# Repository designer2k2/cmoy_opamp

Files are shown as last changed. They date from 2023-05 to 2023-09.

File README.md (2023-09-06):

# cmoy_opamp
flexible cmoy style headphone amplifier

it can fit dual or single Op Amp´s, even a ZIF socket is possible for fast Op Amp changes.

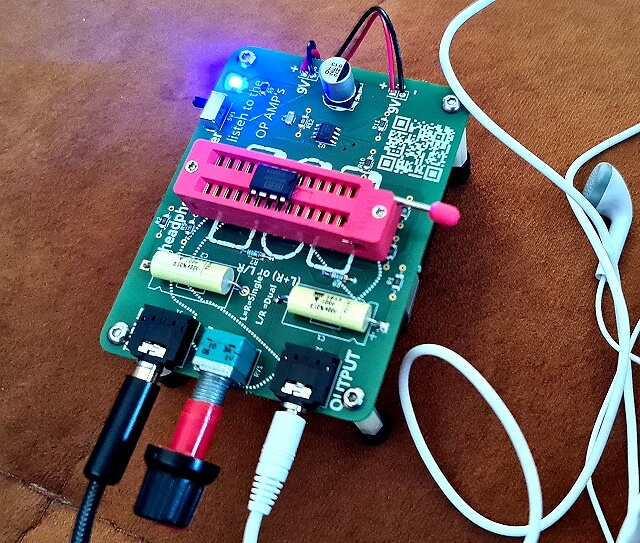
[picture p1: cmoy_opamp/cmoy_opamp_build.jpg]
cmoy schematic


## The schematics:
cmoy schematic
It looks a bit strange, but its to fit both SMD and THT parts, and the different Op Amps.

One selection was made specifically, thats the virtual ground with a resistor voltage divider and voltage follower with the LMH6642. Like this it adds another Op Amp, fitting the Op Amp challenge better.

## PCB:
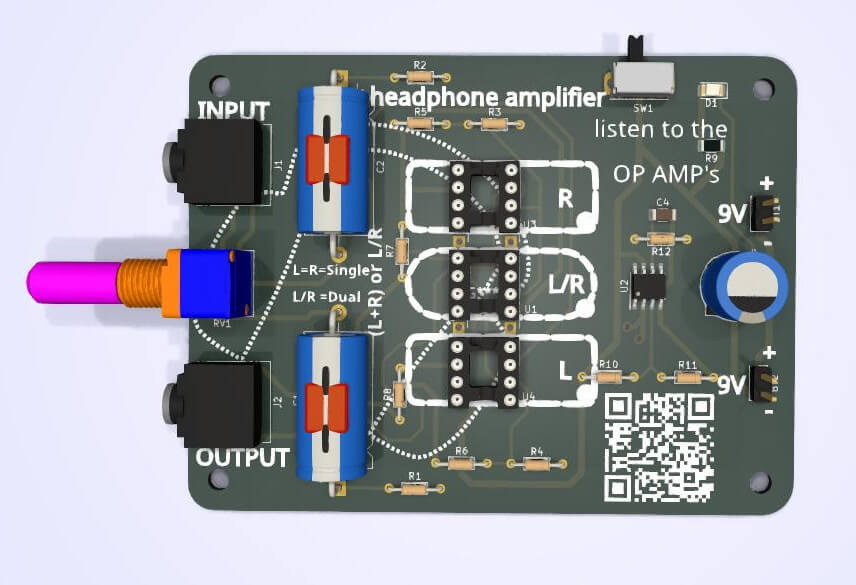
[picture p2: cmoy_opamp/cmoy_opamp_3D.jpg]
cmoy schematic


its made to fit single or dual Op Amps:

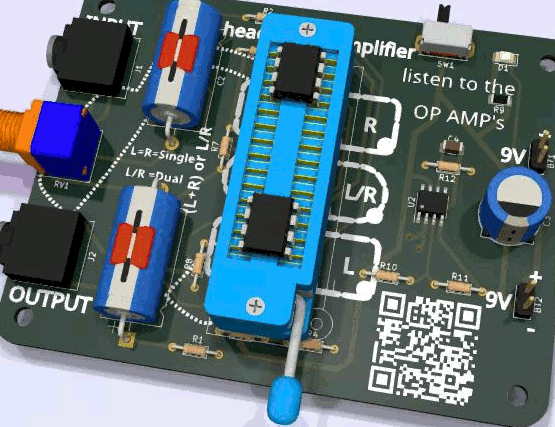
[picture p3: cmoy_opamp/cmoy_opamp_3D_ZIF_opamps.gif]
cmoy schematic


To listen to many different IC´s a ZIF Socket is helpful:

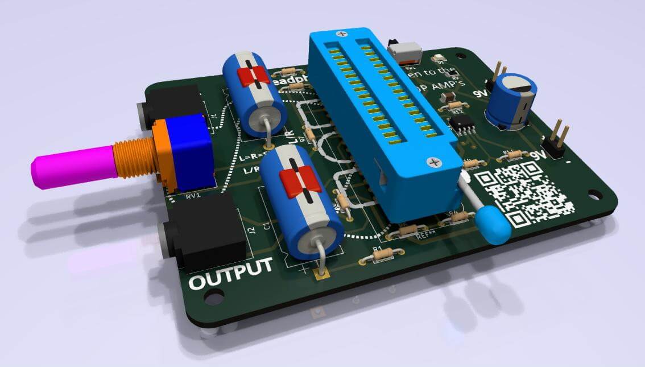
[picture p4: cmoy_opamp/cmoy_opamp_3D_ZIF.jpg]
cmoy schematic


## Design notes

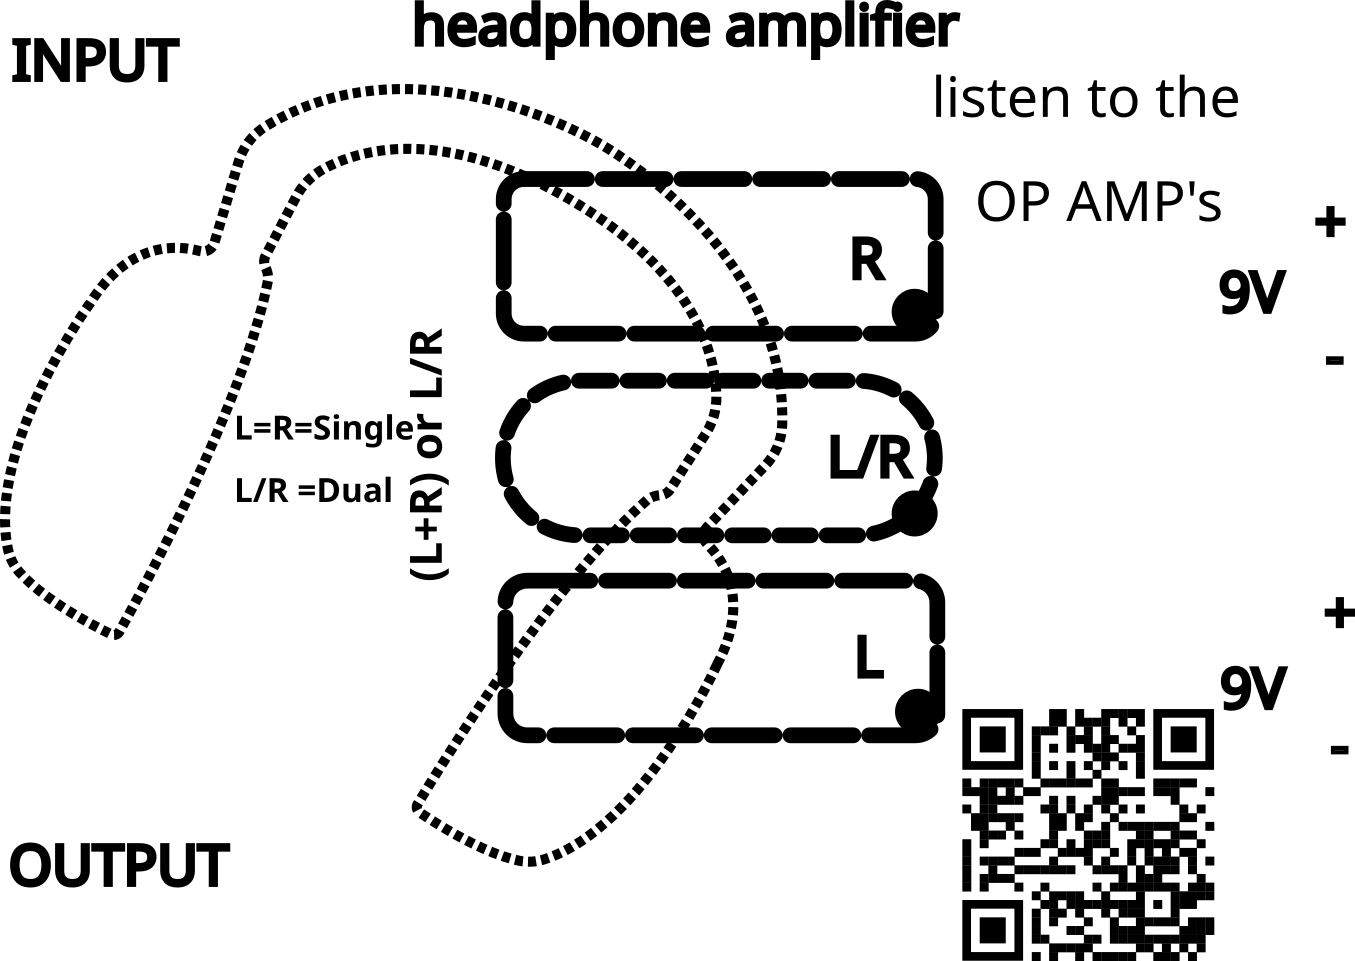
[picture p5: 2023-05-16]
cmoy_opamp/cmoy_opamp-brd.png

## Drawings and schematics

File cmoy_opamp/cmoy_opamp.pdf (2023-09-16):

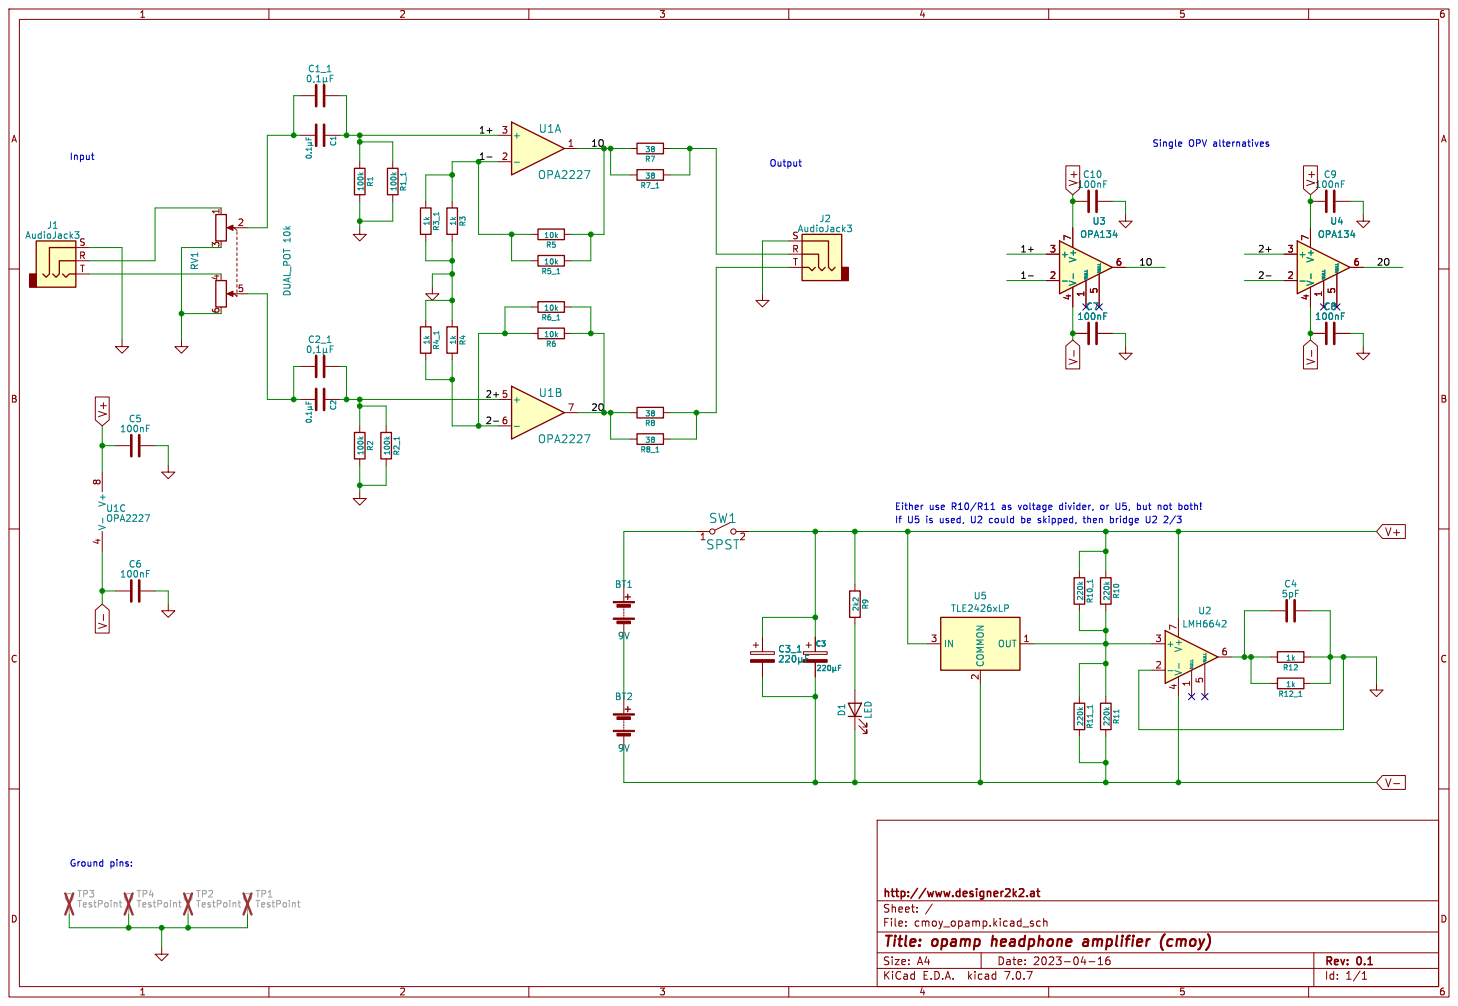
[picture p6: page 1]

If U5 is used, U2 could be skipped, then bridge U2 2/3 C7

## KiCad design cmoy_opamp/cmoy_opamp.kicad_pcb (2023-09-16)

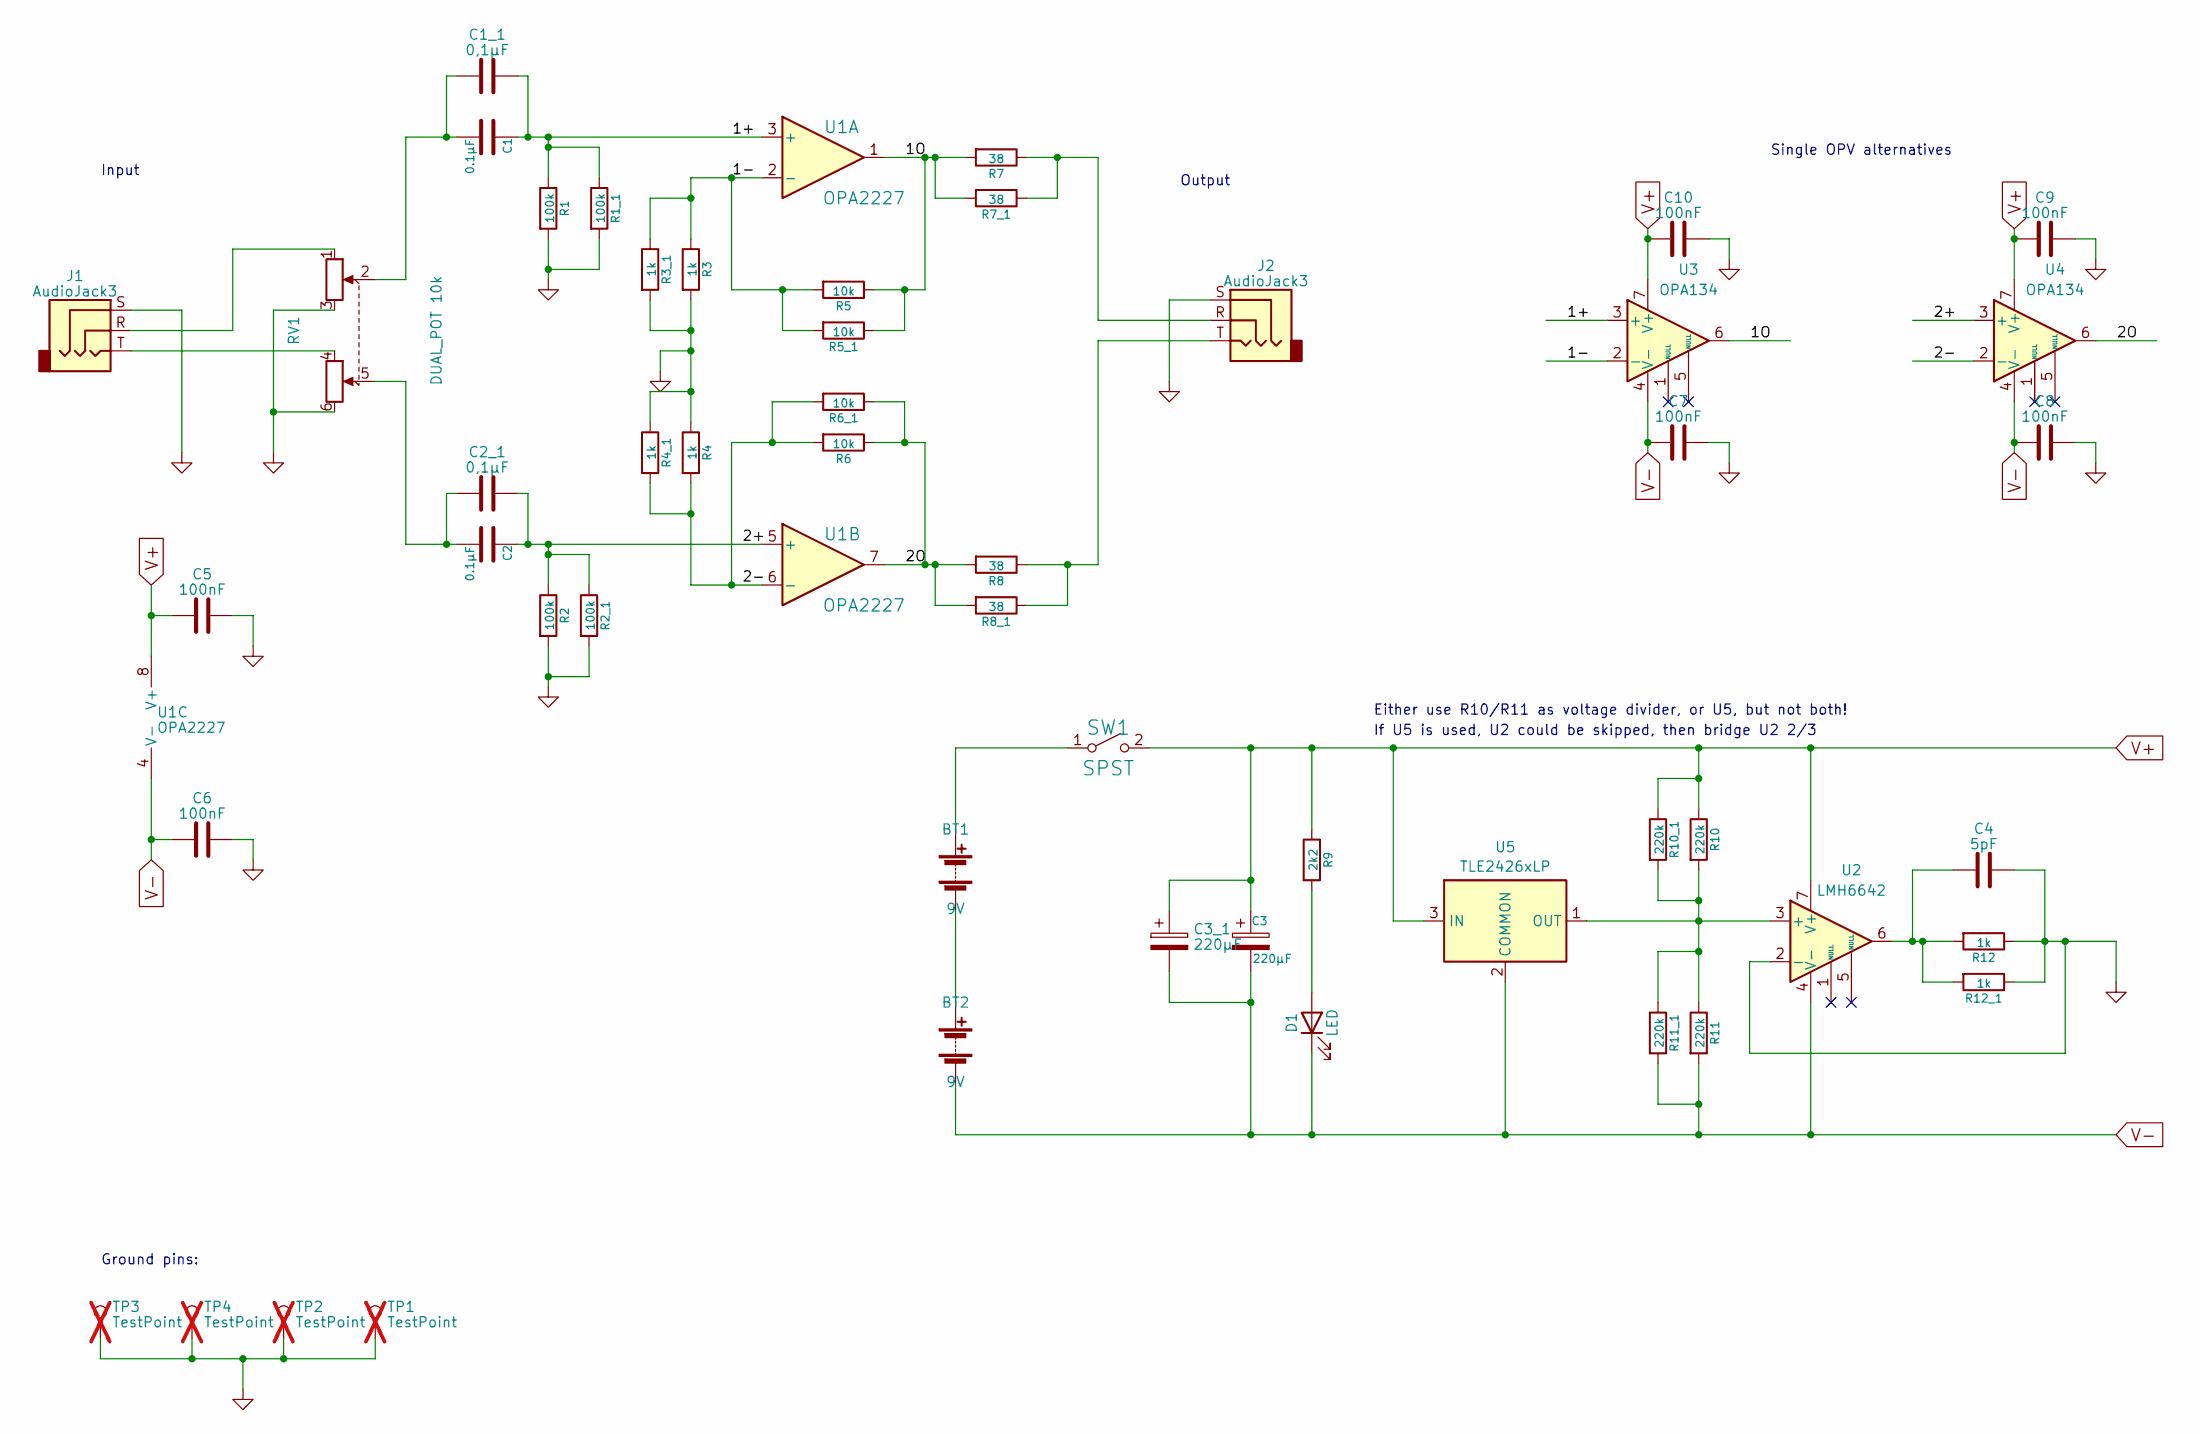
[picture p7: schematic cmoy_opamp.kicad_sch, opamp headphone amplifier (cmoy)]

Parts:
BT1, BT2: 9V; PinHeader_2x01_P2.54mm_Vertical
C1, C2: 0.1µF; CP_Axial_L20.0mm_D10.0mm_P26.00mm_Horizontal; Part MKT1813410405
C1_1, C2_1: 0,1µF; C_Rect_L7.0mm_W6.0mm_P5.00mm; Part BFC237011105
C3: 220µF; CP_Elec_8x10
C3_1: 220µF; CP_Radial_D10.0mm_P3.50mm
C4: 5pF; C_1206_3216Metric
C5, C6, C7, C8, C9, C10: 100nF; C_1206_3216Metric
D1: LED; LED_1206_3216Metric
J1, J2: AudioJack3; Jack_3.5mm_CUI_SJ1-3523N_Horizontal; Part SJ1-3523N
R1, R2: 100k; R_1206_3216Metric
R1_1, R2_1: 100k; R_Axial_DIN0204_L3.6mm_D1.6mm_P7.62mm_Horizontal
R3, R4, R12: 1k; R_1206_3216Metric
R3_1, R4_1, R12_1: 1k; R_Axial_DIN0204_L3.6mm_D1.6mm_P7.62mm_Horizontal
R5, R6: 10k; R_1206_3216Metric
R5_1, R6_1: 10k; R_Axial_DIN0204_L3.6mm_D1.6mm_P7.62mm_Horizontal
R7, R8: 38; R_1206_3216Metric
R7_1, R8_1: 38; R_Axial_DIN0204_L3.6mm_D1.6mm_P7.62mm_Horizontal
R9: 2k2; R_1206_3216Metric
R10, R11: 220k; R_1206_3216Metric
R10_1, R11_1: 220k; R_Axial_DIN0204_L3.6mm_D1.6mm_P7.62mm_Horizontal
RV1: DUAL_POT 10k; Potentiometer_Alps_RK097_Dual_Horizontal; Part RK09712200HA
SW1: SPST; SW_CuK_OS102011MA1QN1_SPDT_Angled; Part OS102011MA1QN1
TP1, TP2, TP3, TP4: TestPoint; PinSocket_1x01_P2.54mm_Vertical; not fitted
U1: OPA2227; DIP-8_W7.62mm_Socket
U2: LMH6642; SOIC-8_3.9x4.9mm_P1.27mm; Part LMH6642MA
U3, U4: OPA134; DIP-8_W7.62mm_Socket
U5: TLE2426xLP; TO-92

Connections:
/1+: C1.1, C1_1.2, R1.1, R1_1.1, U1.3 (+), U3.3 (+)
/1-: R3.1, R3_1.1, R5.2, R5_1.2, U1.2 (-), U3.2 (-)
/1O: R5.1, R5_1.1, R7.2, R7_1.2, U1.1, U3.6
/2+: C2.1, C2_1.2, R2.1, R2_1.1, U1.5 (+), U4.3 (+)
/2-: R4.2, R4_1.2, R6.2, R6_1.2, U1.6 (-), U4.2 (-)
/2O: R6.1, R6_1.1, R8.2, R8_1.2, U1.7, U4.6
GND: C4.2, C5.2, C6.2, C7.2, C8.2, C9.2, C10.2, J1.S, J2.S, R1.2, R1_1.2, R2.2, R2_1.2, R3.2, R3_1.2, R4.1, R4_1.1, R12.1, R12_1.1, RV1.3, RV1.6, TP1.1, TP2.1, TP3.1, TP4.1, U2.2 (-)
unnamed: BT1.1 (+), SW1.1 (A)
unnamed: BT1.2 (-), BT2.1 (+)
unnamed: C1.2, C1_1.1, RV1.2
unnamed: C2.2, C2_1.1, RV1.5
unnamed: C4.1, R12.2, R12_1.2, U2.6
unnamed: D1.2 (A), R9.2
unnamed: J1.R, RV1.1
unnamed: J1.T, RV1.4
unnamed: J2.R, R7.1, R7_1.1
unnamed: J2.T, R8.1, R8_1.1
unnamed: R10.2, R10_1.2, R11.1, R11_1.1, U2.3 (+), U5.1 (OUT)
V+: C3.1, C3_1.1, C5.1, C9.1, C10.1, R9.1, R10.1, R10_1.1, SW1.2 (B), U1.8 (V+), U2.7 (V+), U3.7 (V+), U4.7 (V+), U5.3 (IN)
V-: BT2.2 (-), C3.2, C3_1.2, C6.1, C7.1, C8.1, D1.1 (K), R11.2, R11_1.2, U1.4 (V-), U2.4 (V-), U3.4 (V-), U4.4 (V-), U5.2 (COMMON)

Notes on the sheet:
If U5 is used, U2 could be skipped, then bridge U2 2/3
Input
Single OPV alternatives
Either use R10/R11 as voltage divider, or U5, but not both!
Ground pins:
Output

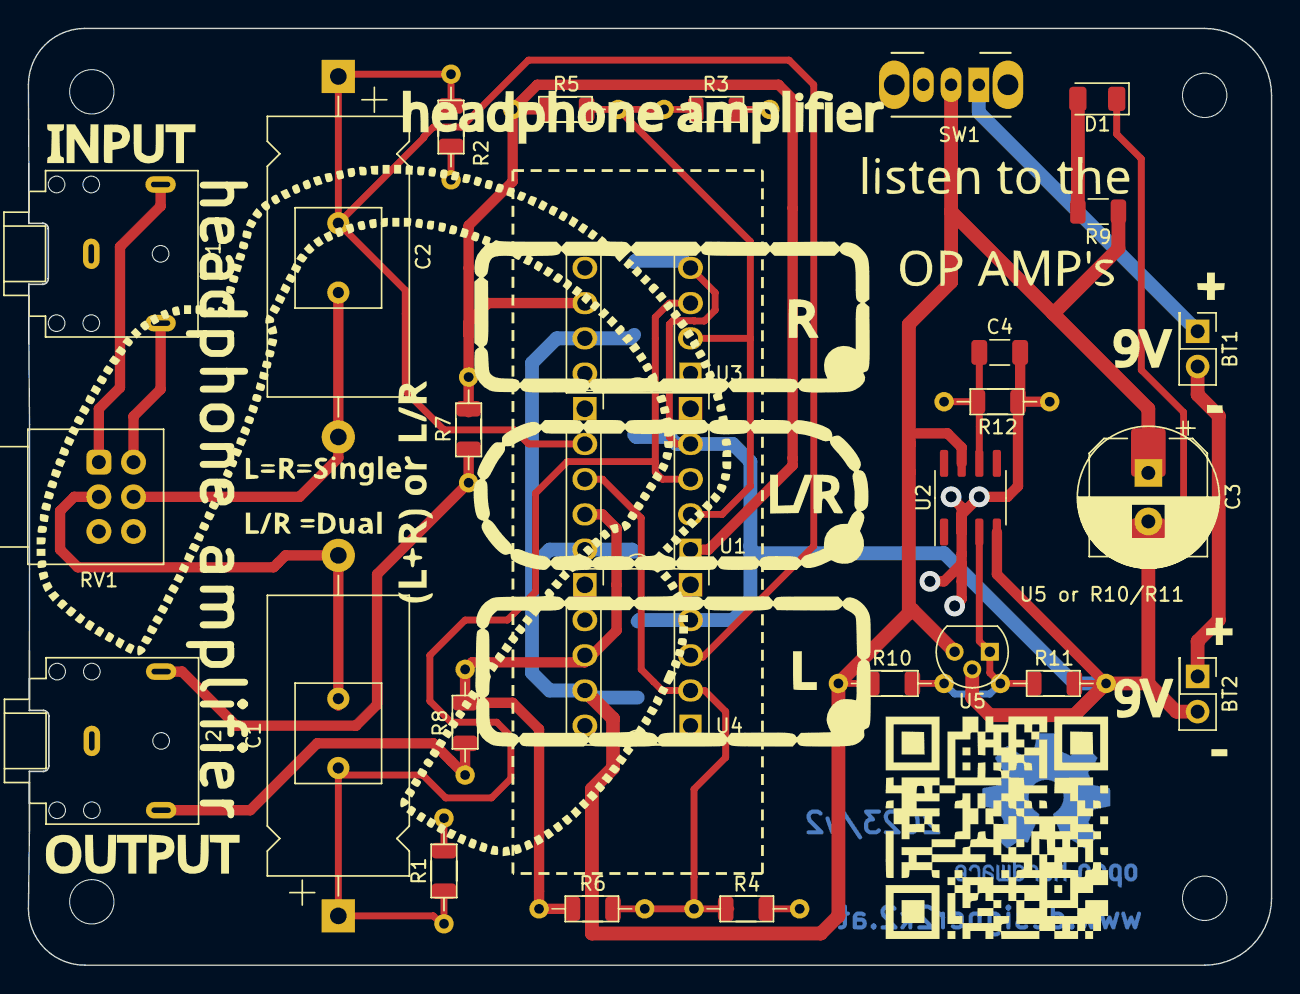
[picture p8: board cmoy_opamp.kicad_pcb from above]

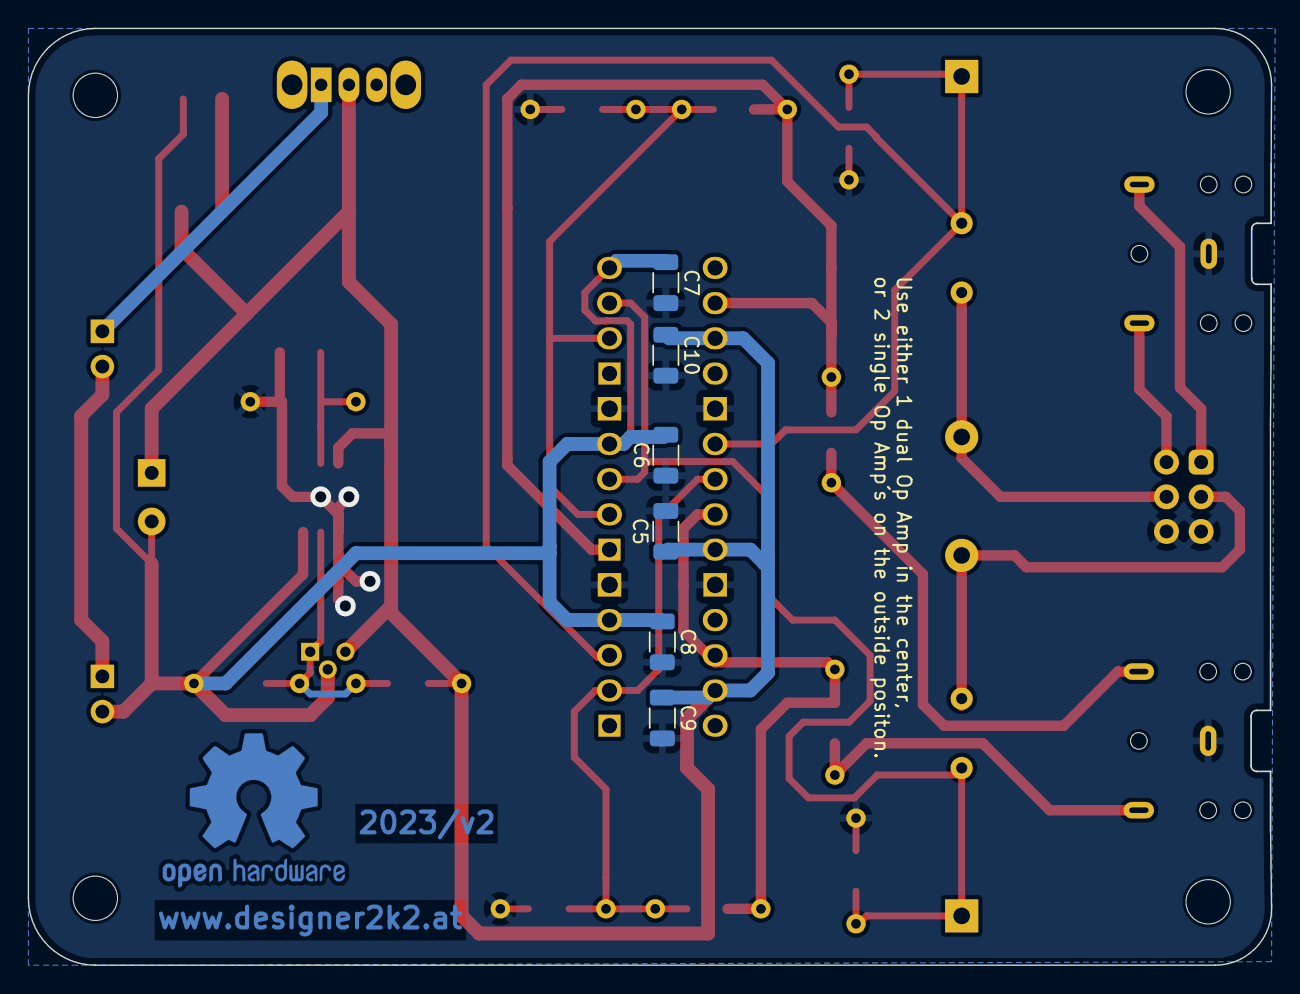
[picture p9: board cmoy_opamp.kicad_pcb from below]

Board: 2 copper layers, 89.7 x 67.6 mm, 52 parts (6 on the bottom side), 20 nets.

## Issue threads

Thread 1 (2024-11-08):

Suggestion: USB-C connector

Ardakilic, 2024-11-08:
Hello,

Can the connector be USB-C ? Micro usb connectors tend to break, at least for me, a lot, and I believe with 5.1k ohm resistors included with the connector, regardless of the voltage, PD could negotiate with the board and it could supply 5v, just like micro usb does to the rest of the board.

Thanks in advance,

Closed 2024-11-08.

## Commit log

2023-04-23 schematic and intial parts placement
    [cmoy_opamp.kicad_pcb, cmoy_opamp.kicad_sch]
2023-04-23 Schematic´s as PDF and SVG
2023-04-27 dual footprint, THT and SMD, first layouting
    [cmoy_opamp.kicad_pcb, cmoy_opamp.kicad_sch]
2023-05-01 PCB Layout complete
    [cmoy_opamp.kicad_pcb, cmoy_opamp.kicad_sch]
2023-05-01 PCB art added
    [cmoy_opamp.kicad_pcb, cmoy_opamp.kicad_sch]
2023-05-01 PCB Version ready to order
    [cmoy_opamp.kicad_pcb]
2023-05-03 Documentation files updated
    [cmoy_opamp.kicad_pcb, cmoy_opamp.kicad_sch]
2023-05-09 replace some rescue lib symbols with built in ones
    [cmoy_opamp.kicad_pcb, cmoy_opamp.kicad_sch]
2023-05-13 fully remove rescue lib reference
    [cmoy_opamp.kicad_pcb, cmoy_opamp.kicad_sch]
2023-05-13 better 3D image
    - all 3d models added
    - use the raytracing option with floor
    [cmoy_opamp.kicad_pcb]
2023-05-13 add ZIF image
    [cmoy_opamp.kicad_pcb]
2023-05-16 Bugfix ZIF socket against R3/4/5/6
    Moving R3/3/4/5/6 a bit to the outside to have clearance for the ZIF socket.
    Like this the ZIF socket can sit flush and does not need to be stacked on DIL socket´s.
    [cmoy_opamp.kicad_pcb, cmoy_opamp.kicad_sch]
2023-09-04 change drilling to fit zif socket
    0,8mm increased to 1,1mm to fit the 0,9mm ZIF socket pins
    [cmoy_opamp.kicad_pcb, cmoy_opamp.kicad_sch]
2023-09-16 Add TLE2426 as option
    TLE2426 option alternative to R10/R11 voltage divider
    [cmoy_opamp.kicad_pcb, cmoy_opamp.kicad_sch]
